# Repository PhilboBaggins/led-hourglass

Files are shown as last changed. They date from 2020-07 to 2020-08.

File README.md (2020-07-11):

# LED Hourglass

Addressable LEDs in the shape of an hourglass.

## Licence

Copyright © 2020 Phil Baldwin

This work is licensed under a Creative Commons Attribution-ShareAlike 4.0 International License.

You should have received a copy of the license along with this work. If not, see <http://creativecommons.org/licenses/by-sa/4.0/>.

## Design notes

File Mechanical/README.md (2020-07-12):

Mechanical design for LED Hourglass
===================================

<table cellspacing="0" cellpadding="0" border="1">
  <colgroup>
    <col span="1" style="width: 40%;">
    <col span="1" style="width: 30%;">
    <col span="1" style="width: 20%;">
  </colgroup>
  <tr>
    <th>Stackup (side view)</th>
    <th>Description</th>
    <th>Files for laser cutting</th>
  </tr>
  <tr>
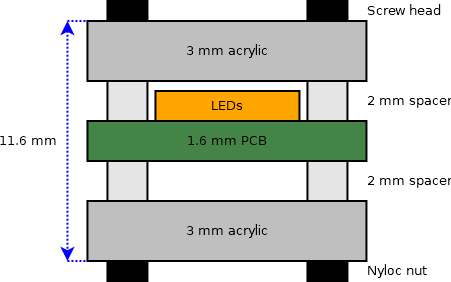
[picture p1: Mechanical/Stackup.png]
    <td></td>
    <td>The <a href="./hourglass-panel.svg">hourglass-panel.svg</a> design is cut out of a piece of acrylic (something like this <a href="https://www.ponoko.com/materials/glass-green-acrylic">glass green acrylic</a>) and placed either side of the PCB with plastic unthreaded stand-offs in between. A screw goes in each corner goes through the acrylic, spacers & the PCB and secure with a nyloc nut to hold he whole thing together.</td>
    <td></td>
  </tr>
  <tr>
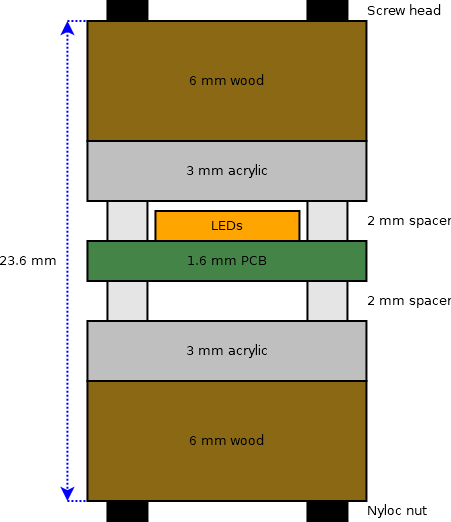
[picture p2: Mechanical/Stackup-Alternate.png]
    <td></td>
    <td>The <a href="./hourglass-glass.svg">hourglass-glass.svg</a> design is cut out of a piece of acrylic (something like this <a href="https://www.ponoko.com/materials/glass-green-acrylic">glass green acrylic</a>) and the <a href="./hourglass-frame.svg">hourglass-frame.svg</a> design is cut out of some kind of wood (like this <a href="https://www.ponoko.com/materials/macrocarpa-hardwood">macrocarpa hardwood</a>). One piec of each is  placed either side of the PCB with plastic unthreaded stand-offs between the PCB and acrylic. A screw goes in each corner goes through the acrylic, wood, spacers & the PCB and secure with a nyloc nut to hold he whole thing together.</td>
    <td></td>
  </tr>
</table>

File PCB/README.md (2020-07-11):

# LED Hourglass



Addressable LEDs in the shape of an hourglass.

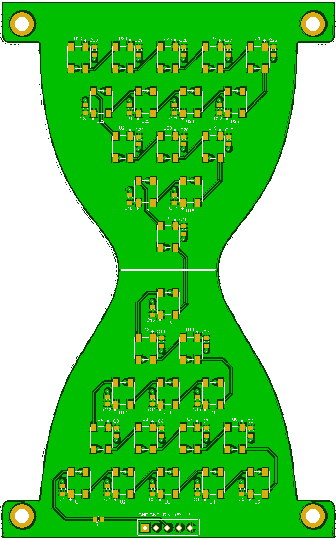
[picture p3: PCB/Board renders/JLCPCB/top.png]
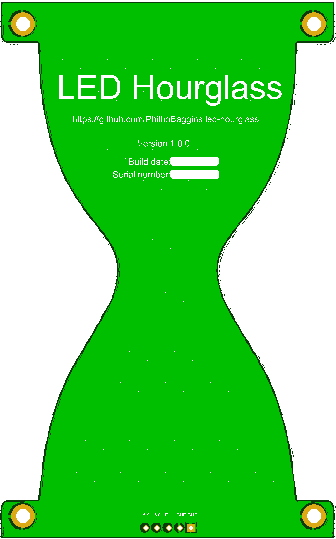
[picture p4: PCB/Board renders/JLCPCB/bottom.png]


## Design files

This board was designed using the [Upverter](https://upverter.com) web service.

The schematic, board layout and bill of materials can be viewed [here](https://upverter.com/design/trebuchetindustries/758f8a002dd9bb0f/led-hourglass/). Exports from Upverter are [available in a subdirectory](./Upverter%20exports).

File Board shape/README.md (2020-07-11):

Board outline for hourglass shaped PCB
======================================

The shape is drawn" in [Inkscape](https://inkscape.org/) (source file: [hourglass.svg](./hourglass.svg)) and then exported in [DXF](./hourglass.dxf) format using [OpenScad](http://www.openscad.org/) (see the [Makefile](./Makefile) for more details).

The intention is to import the DXF into PCB design software and use it as a PCB's outline mechanical layer.

## Licence

Copyright © 2020 Phil Baldwin

This work is licensed under a Creative Commons Attribution-ShareAlike 4.0 International License.

You should have received a copy of the license along with this work. If not, see <http://creativecommons.org/licenses/by-sa/4.0/>.

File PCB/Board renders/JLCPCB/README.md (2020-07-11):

This directory contains pictures of the PCB exported from the [JLC PCB](https://jlcpcb.com/) service. These pictures are based off the gerber files in the [Upverter exports](../Upverter%20exports/) directory.

<table cellspacing="0" cellpadding="0" border="0" width="100%">
  <tr>
    <th>Top</th>
    <th>Bottom</th>
  </tr>
  <tr>
    <td>Board design - Top</td>
    <td>Board design - Bottom</td>
  </tr>
</table>

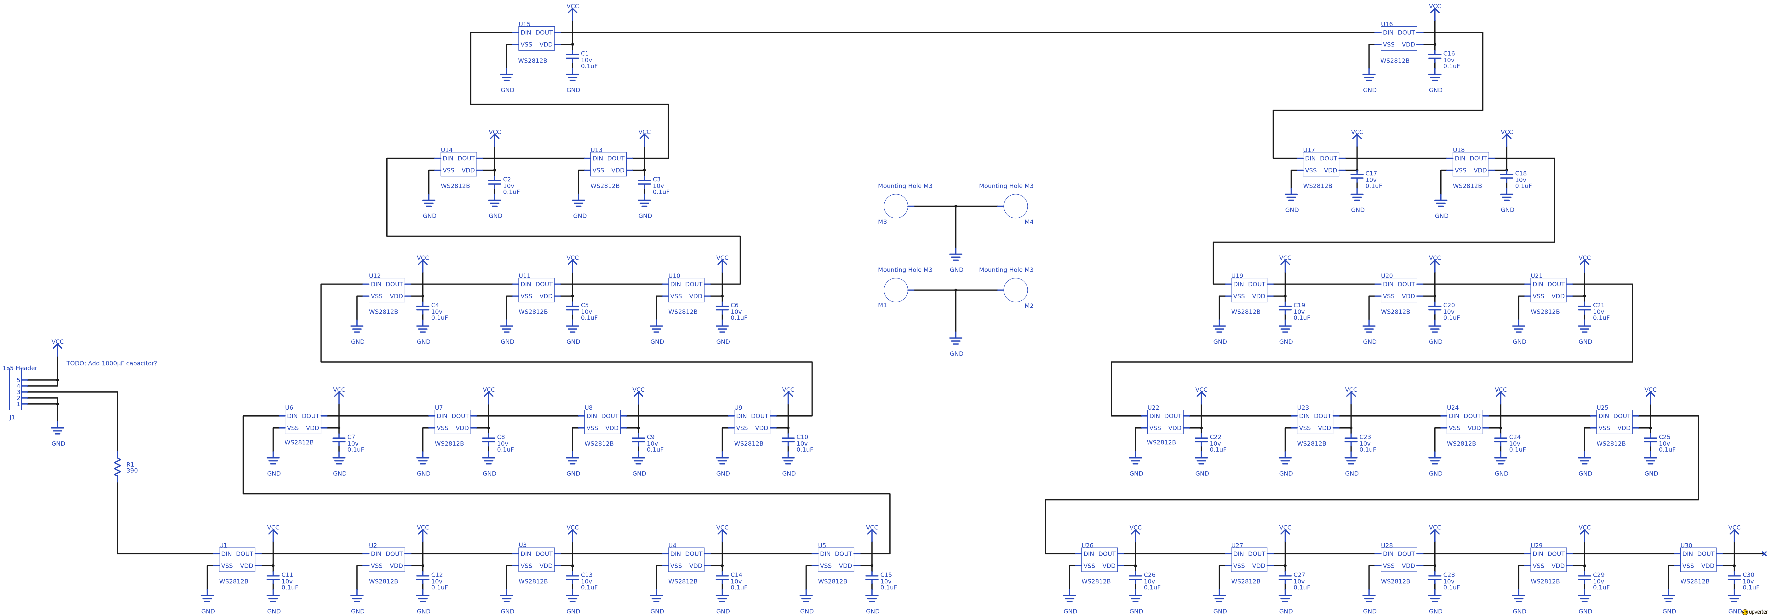
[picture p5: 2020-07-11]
PCB/Upverter exports/Schematic.png

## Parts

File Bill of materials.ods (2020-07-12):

Production quantity: | 30
Item | Quantity | Production quantity
PCB | 1 | 30
PCB BOM items | 1 | 30
Acrylic panel | 2 | 60
M3 2 mm spacer | 8 | 240 | https://www.aliexpress.com/item/4000800414329.html
M3x15 Phillips pan head screw | 4 | 120
M3 nyloc nut | 4 | 120

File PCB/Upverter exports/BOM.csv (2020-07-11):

Reference Designator | Description | Manufacturer | Manufacturer Part Number | Suppliers | Package | Quantity | Capacitance | Voltage | Is Generic | Symbol Type | Centroid Not Specified | Resistance | Reach Svhc | Min Operating Temperature | Current Rating | Conn 3 Type | Ro Hscompliant | Component Link 1 Description | Max Operating Temperature | Pins | Imported | Tolerance | Vault Guid | Shielding | Datasheet Version | Verified Attributes | Component Link 1 Url | Footprint Variant Name 0 | Ciiva Ids | Vault Revision | Release Date | Verified Geometry | Mount | Length | Import Ts | Radiation Hardening | Lead Pitch | Verified Pin Names | Package Description | Imported From | Conn 0 Type | Package Quantity | Verified Pad Assignment | Height | Packaging | Case Package | Conn 1 Type | Conn 2 Type
C1 C10 C11 C12 C13 C14 C15 C16 C17 C18 C19 C2 C20 C21 C22 C23 C24 C25 C26 C27 C28 C29 C3 C30 C4 C5 C6 C7 C8 C9 | Generic Capacitor (Non-Polarized) (1e-07F) | Generic | Capacitor (1e-07F) |  | 0603 (1608 metric) | 30 | 1e-07F | 10v | true | Capacitor
J1 | Header - 5 pin, 0.1" pitch |  | 1x5 Header |  |  | 1
M1 M2 M3 M4 | Mounting Hole M3 | Generic | Mounting Hole M3 |  |  | 4 |  |  |  |  | No
R1 | Generic Resistor (390) | Generic | Resistor (390) |  | 0603 (1608 metric) | 1 |  |  | true | Resistor |  | 390
U1 U10 U11 U12 U13 U14 U15 U16 U17 U18 U19 U2 U20 U21 U22 U23 U24 U25 U26 U27 U28 U29 U3 U30 U4 U5 U6 U7 U8 U9 | ADAI-WS2812B-4 | Adafruit Industries | WS2812B |  | WS2812B | 30 |  |  |  |  |  |  | No SVHC | -55 degC | 240 mA | input | true | Manufacturer URL | 125 degC | 2 | yes | 10% | F56B6EC9-4E76-4E2F-9058-8D3EE8A248DE | Unshielded | May-13 | true | https://www.adafruit.com/ | Manufacturer Recommended | 20395447 | 33156DEA-FED9-4B72-92E0-2F21AD4FE014 | 1475030199 | true | Through Hole | 12.2 mm | 1521859311 | No | 5 mm | true | 4-Pin Surface Mount Device, Body 5 x 5 mm, Pitch 3.3 mm | vault | power | 200 | true | 12.2 mm | Bulk | Radial | output | power

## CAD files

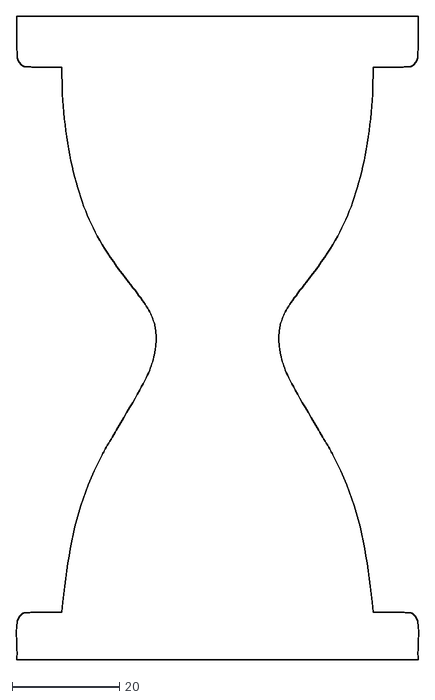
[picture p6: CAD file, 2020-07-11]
Board shape/hourglass.dxf
75.0 x 120.0

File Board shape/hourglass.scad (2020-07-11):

import("hourglass.svg");

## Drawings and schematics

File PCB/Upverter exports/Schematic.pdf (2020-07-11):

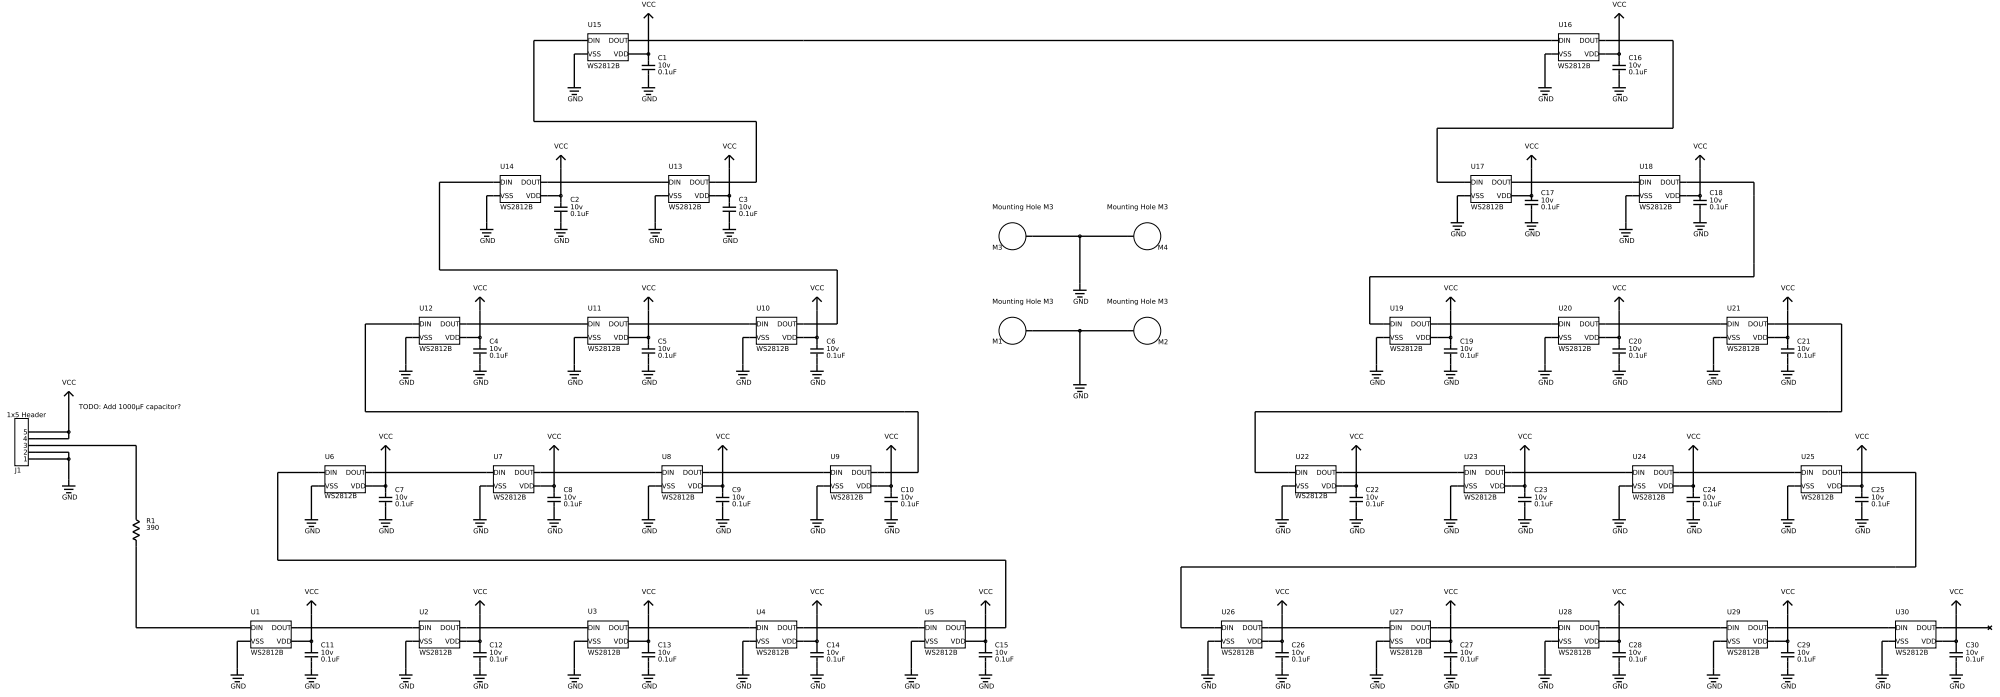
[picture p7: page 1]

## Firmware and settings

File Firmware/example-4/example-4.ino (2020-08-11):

#include "FastLED.h"

// An hourglass contains 30 LEDs
#define NUM_LEDS 30

// Define the pin on your MCU board, which is connected to the "DIN" on the hourglass board
#define DATA_PIN 0

CRGB leds[NUM_LEDS];

CRGB HOURGLASS_COLOUR(5, 0, 0); // Dim red

//const int COUNTDOWN_SECS = 15;
const int COUNTDOWN_SECS = 60;

const int SECONDS_PER_PIXEL = COUNTDOWN_SECS / (NUM_LEDS / 2);

void setHourglass(int seconds)
{
    // Colour top half of hourglass
    for (int i = 0; i < NUM_LEDS / 2; i++)
    {
        if (i < seconds / SECONDS_PER_PIXEL)
            leds[i] = CRGB::Black;
        else
            leds[i] = HOURGLASS_COLOUR;
    }

    // Colour bottom half of hourglass
    for (int i = 0; i < NUM_LEDS / 2; i++)
    {
        if (i <= seconds / SECONDS_PER_PIXEL)
            leds[NUM_LEDS - 1 - i] = HOURGLASS_COLOUR;
        else
            leds[NUM_LEDS - 1 - i] = CRGB::Black;
    }

    FastLED.show();
}

void setup()
{
    FastLED.addLeds<WS2812B, DATA_PIN, GRB>(leds, NUM_LEDS);
}

void loop()
{
    setHourglass(millis() / 1000 % COUNTDOWN_SECS);
    delay(100);
}

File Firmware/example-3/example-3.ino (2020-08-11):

#include "FastLED.h"

// An hourglass contains 30 LEDs
#define NUM_LEDS 30

// Define the pin on your MCU board, which is connected to the "DIN" on the hourglass board
#define DATA_PIN 0

CRGB leds[NUM_LEDS];

void setJustOneLED(int ledIdx, CRGB colour)
{
    for (int i = 0; i < NUM_LEDS; i++)
    {
        leds[i] = CRGB::Black;
    }
    leds[ledIdx] = colour;
    FastLED.show();
}

void setup()
{
    FastLED.addLeds<WS2812B, DATA_PIN, GRB>(leds, NUM_LEDS);
    randomSeed(analogRead(0));
}

void loop()
{
    const int ledIdx = random(0, 30);
    const int red = random(0, 255);
    const int green = random(0, 255);
    const int blue = random(0, 255);
    const int delayMs = random(50, 200);
    setJustOneLED(ledIdx, CRGB(red, green, blue));
    delay(delayMs);
}

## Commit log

2020-07-11 Convert hourglass.svg to hourglass.dxf
    [hourglass.dxf, hourglass.scad]
2020-07-11 Add Board outline/REDME.md
2020-07-11 Resize hourglass shape to 55mm x 85mm
    [hourglass.dxf]
2020-07-11 Resize hourglass shape to 75mm x 120mm
    [hourglass.dxf]
2020-07-11 Add Upverter exports for version 1.0.0 of PCB design
    [BOM.csv, PickAndPlace.csv, layers.cfg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]
2020-07-11 Add PCB/README.md
2020-07-11 Add board renders for version 1.0.0 of the PCB
2020-07-11 Add correct PCBs.io board renders for version 1.0.0 of PCB
    Previous files were from another board (accidently added)
2020-07-11 Add PCB\Board renders\JLCPCB\README.md
2020-07-11 Convert Upverter's pick and place file to the format required by JLC PCB
    [PickAndPlace.csv]
2020-07-12 Add LEDs to stackup diagram
2020-07-12 Add very rough bill of materials
    [Bill of materials.ods]
2020-08-11 Add 4th example program: An hourglass count down timer ... not fully tested yet, may not be accurate
    And it's based on Arduino's millis() function, so it's never going to be especially accurate .... but it's not meant to be.
